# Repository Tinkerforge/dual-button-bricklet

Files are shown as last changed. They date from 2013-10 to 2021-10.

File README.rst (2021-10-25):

Dual Button Bricklet
====================

This repository contains the firmware source code and the hardware design
files. The documentation generator configs can be found at
https://github.com/Tinkerforge/generators

Repository Content
------------------

software/:
 * examples/: Examples for all supported languages
 * build/: Compiled files
 * src/: Source code of firmware
 * Makefile: Makefile to build project

hardware/:
 * Contains KiCad project files and additionally schematics as PDF

datasheets/:
 * Contains datasheets for sensors and complex ICs that are used

Hardware
--------

The hardware is designed with the open source EDA Suite KiCad
(http://www.kicad.org). Before you are able to open the files,
you have to install the Tinkerforge kicad-libraries
(https://github.com/Tinkerforge/kicad-libraries). You can either clone
them directly in hardware/ or clone them in a separate folder and
symlink them into hardware/
(ln -s kicad_path/kicad-libraries project_path/hardware). After that you
can open the .pro file in hardware/ with KiCad and from there view and
modify the schematics and the PCB layout.

Software
--------

If you want to do your own Brick/Bricklet firmware development we highly
recommend that you use our build environment setup script and read the
tutorial (https://www.tinkerforge.com/en/doc/Tutorials/Tutorial_Build_Environment/Tutorial.html).

To compile the C code we recommend you to install the newest GNU Arm Embedded
Toolchain (https://launchpad.net/gcc-arm-embedded/+download).
You also need to install bricklib (https://github.com/Tinkerforge/bricklib)
and brickletlib (https://github.com/Tinkerforge/brickletlib).

You can either clone it directly in software/src/ or clone it in a
separate folder and symlink it into software/src/
(ln -s bricklib_path/bricklib project_path/software/src/ and
ln -s brickletlib_path/brickletlib project_path/software/src/).
Finally make sure to have CMake installed
(http://www.cmake.org/cmake/resources/software.html).

After that you can build the firmware by invoking make in software/.
The firmware (.bin) can then be found in software/build/ and uploaded
with brickv (click button "Flashing" on start screen).

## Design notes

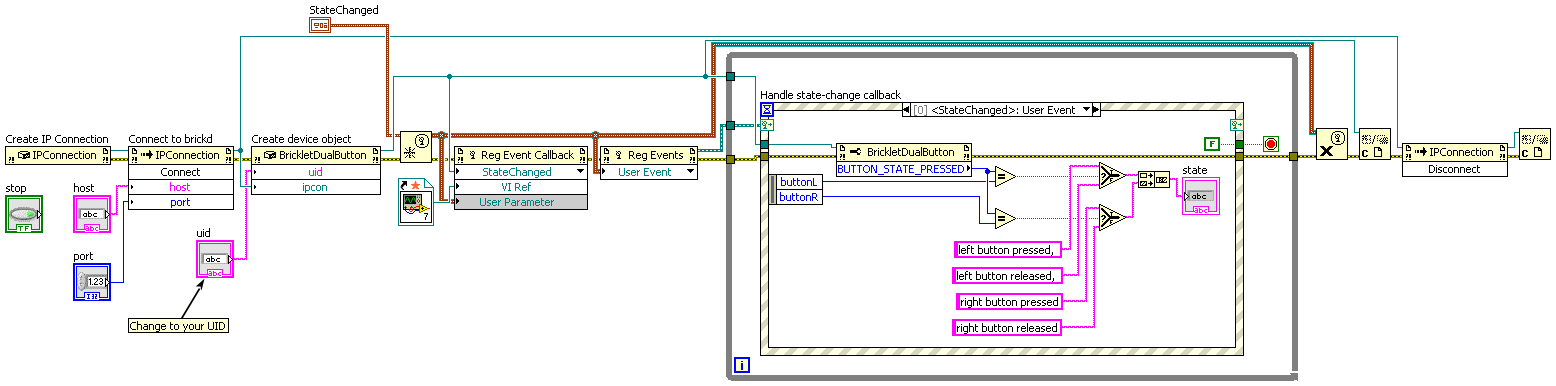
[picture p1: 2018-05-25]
software/examples/labview/Example Callback.vi.png

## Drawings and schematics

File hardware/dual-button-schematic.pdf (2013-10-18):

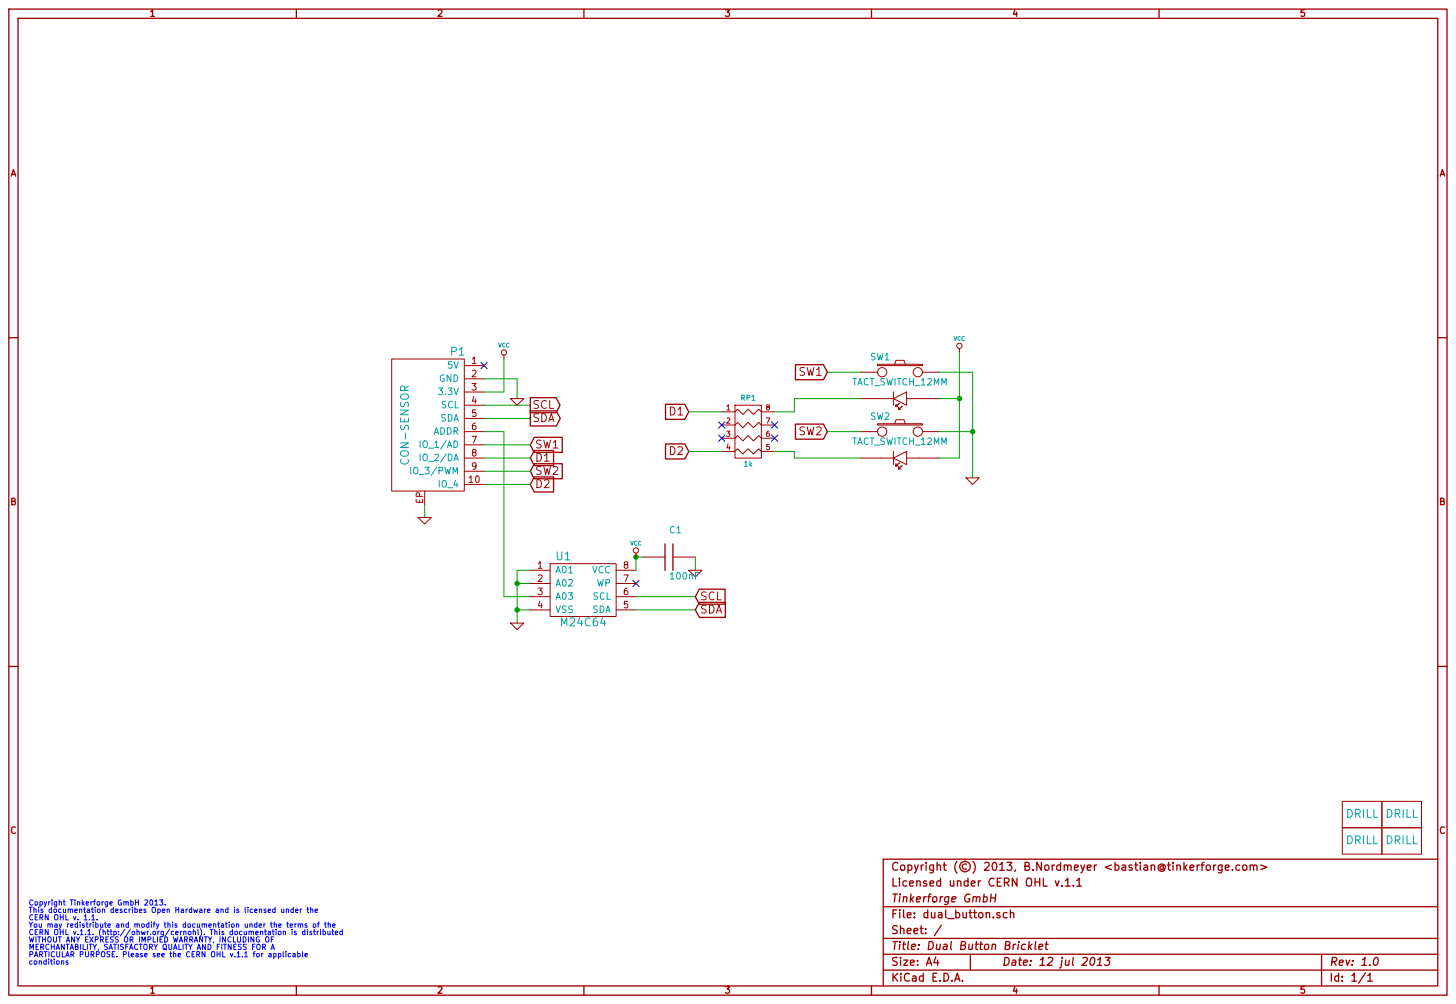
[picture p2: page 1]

Copyright (©) 2013, B.Nordmeyer <bastian@tinkerforge.com>
Licensed under CERN OHL v.1.1
Tinkerforge GmbH
Id: 1/1 Title: Dual Button Bricklet File: dual_button.sch
Sheet: /

Copyright Tinkerforge GmbH 2013. This documentation describes Open Hardware and is licensed under the CERN OHL v. 1.1. You may redistribute and modify this documentation under the terms of the CERN OHL v.1.1. (http://ohwr.org/cernohl). This documentation is distributed WITHOUT ANY EXPRESS OR IMPLIED WARRANTY, INCLUDING OF MERCHANTABILITY, SATISFACTORY QUALITY AND FITNESS FOR A

PARTICULAR PURPOSE. Please see the CERN OHL v.1.1 for applicable

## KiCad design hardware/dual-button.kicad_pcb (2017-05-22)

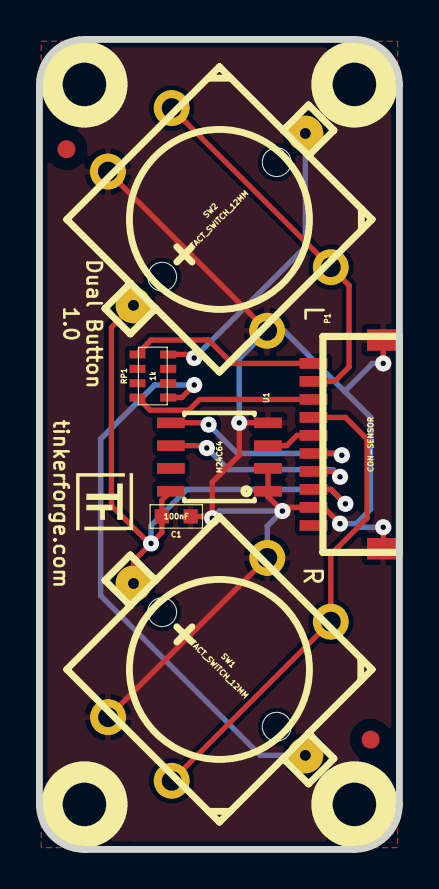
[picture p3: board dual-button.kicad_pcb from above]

Board: 2 copper layers, 20.0 x 45.0 mm, 15 parts (0 on the bottom side), 11 nets.

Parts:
C1: 100nF; 0603
Fiducial_Mark: VAL**; Fiducial_Mark
Fiducial_Mark#2: VAL**; Fiducial_Mark
P1: CON-SENSOR
RP1: 1k; 4X0603
Ref**: Val**; Logo_31x31
SW1, SW2: TACT_SWITCH_12MM; TACT_SWITCH_12mm
U1: M24C64; SOIC8
U2, U3, U4, U5: DRILL; DRILL_NP
VAL: WEEE_7mm
VAL#2: CE_5mm

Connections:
D1: P1.8, RP1.1
D2: P1.10, RP1.4
GND: C1.1, P1.2, P1.EP, SW1.3, SW2.3, U1.1, U1.2, U1.4
unnamed: RP1.5, SW2.2
unnamed: RP1.8, SW1.2
unnamed: P1.6, U1.3
SCL: P1.4, U1.6
SDA: P1.5, U1.5
SW1: P1.7, SW1.4
SW2: P1.9, SW2.4
VCC: C1.2, P1.3, SW1.1, SW2.1, U1.8

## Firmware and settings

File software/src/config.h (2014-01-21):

/* dual-button-bricklet
 * Copyright (C) 2013 Olaf Lüke <olaf@tinkerforge.com>
 *
 * config.h: Dual Button Bricklet specific configuration
 *
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
 * You should have received a copy of the GNU Lesser General Public
 * License along with this library; if not, write to the
 * Free Software Foundation, Inc., 59 Temple Place - Suite 330,
 * Boston, MA 02111-1307, USA.
 */

#ifndef CONFIG_H
#define CONFIG_H

#include <stdint.h>
#include <stdbool.h>

#include "bricklib/drivers/board/sam3s/SAM3S.h"

#include "dual-button.h"

#define BRICKLET_FIRMWARE_VERSION_MAJOR 2
#define BRICKLET_FIRMWARE_VERSION_MINOR 0
#define BRICKLET_FIRMWARE_VERSION_REVISION 2

#define BRICKLET_HARDWARE_VERSION_MAJOR 1
#define BRICKLET_HARDWARE_VERSION_MINOR 0
#define BRICKLET_HARDWARE_VERSION_REVISION 0

#define BRICKLET_DEVICE_IDENTIFIER 230

#define PIN_BUTTON_R (BS->pin1_ad)
#define PIN_LED_R    (BS->pin2_da)
#define PIN_BUTTON_L (BS->pin3_pwm)
#define PIN_LED_L    (BS->pin4_io)

#define LOGGING_LEVEL LOGGING_DEBUG
#define DEBUG_BRICKLET 0

#define BRICKLET_NO_OFFSET
#define INVOCATION_IN_BRICKLET_CODE

typedef struct {
	uint8_t button_r;
	uint8_t button_l;
	uint8_t led_r;
	uint8_t led_l;

	uint16_t button_r_debounce;
	uint16_t button_l_debounce;

	bool state_changed;

	uint32_t tick;
} BrickContext;

#endif

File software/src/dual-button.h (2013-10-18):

/* dual-button-bricklet
 * Copyright (C) 2013 Olaf Lüke <olaf@tinkerforge.com>
 *
 * dual-button.h: Implementation of Dual Button Bricklet messages
 *
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
 * You should have received a copy of the GNU Lesser General Public
 * License along with this library; if not, write to the
 * Free Software Foundation, Inc., 59 Temple Place - Suite 330,
 * Boston, MA 02111-1307, USA.
 */

#ifndef DUAL_BUTTON_H
#define DUAL_BUTTON_H

#include <stdint.h>
#include "bricklib/com/com_common.h"

#define BUTTON_L 0
#define BUTTON_R 1

#define LED_L 0
#define LED_R 1

#define BUTTON_STATE_PRESSED 0
#define BUTTON_STATE_RELEASED 1

#define BUTTON_DEBOUNCE_TIME 25 // in ms

#define LED_STATE_AUTO_TOGGLE_ON 0
#define LED_STATE_AUTO_TOGGLE_OFF 1
#define LED_STATE_ON 2
#define LED_STATE_OFF 3

#define FID_SET_LED_STATE 1
#define FID_GET_LED_STATE 2
#define FID_GET_BUTTON_STATE 3
#define FID_STATE_CHANGED 4
#define FID_SET_SELECTED_LED_STATE 5

typedef struct {
	MessageHeader header;
} __attribute__((__packed__)) StandardMessage;

typedef struct {
	MessageHeader header;
	uint8_t led_l;
	uint8_t led_r;
} __attribute__((__packed__)) SetLEDState;

typedef struct {
	MessageHeader header;
} __attribute__((__packed__)) GetLEDState;

typedef struct {
	MessageHeader header;
	uint8_t led_l;
	uint8_t led_r;
} __attribute__((__packed__)) GetLEDStateReturn;

typedef struct {
	MessageHeader header;
} __attribute__((__packed__)) GetButtonState;

typedef struct {
	MessageHeader header;
	uint8_t button_l;
	uint8_t button_r;
} __attribute__((__packed__)) GetButtonStateReturn;

typedef struct {
	MessageHeader header;
	uint8_t button_l;
	uint8_t button_r;
	uint8_t led_l;
	uint8_t led_r;
} __attribute__((__packed__)) StateChanged;

typedef struct {
	MessageHeader header;
	uint8_t led;
	uint8_t state;
} __attribute__((__packed__)) SetSelectedLEDState;

void set_led_state(const ComType com, const SetLEDState *data);
void get_led_state(const ComType com, const GetLEDState *data);
void get_button_state(const ComType com, const GetButtonState *data);
void set_selected_led_state(const ComType com, const SetSelectedLEDState *data);

void next_led_toggle_state(const uint8_t button);
void send_state_changed_callback(void);

void invocation(const ComType com, const uint8_t *data);
void constructor(void);
void destructor(void);
void tick(const uint8_t tick_type);

#endif

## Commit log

2013-07-23 Initial commit for Dual Button Bricklet
2013-07-23 Add prototype disclaimer to README.rst
2013-09-11 Add examples for Dual Button Bricklet
2013-10-15 hardware files checkin
    [dual_button.kicad_pcb, dual_button.sch]
2013-10-17 Change default LED state to auto-toggle-off
2013-10-18 Add SetSelectedLEDState API for Dual Button Bricklet
2014-01-20 Fix mixup in firmware/hardware version
    [config.h]
2014-01-21 Fix left/right button permutation
    [config.h]
2014-04-02 perl: Unify print style
2015-08-07 Use full device class name in Python example
2016-05-18 c: Add missing device destroy call
2017-05-22 add button diameter marking
    [dual_button.kicad_pcb]
2018-02-20 Cleanup KiCad libraries config
    Ensure LibDir=kicad-libraries and LibName1=tinkerforge.
    Remove special library.
2018-05-11 Rename files
    [dual-button.kicad_pcb, dual-button.sch]
2018-05-28 examples: Unify constant printing style
2021-10-25 Update KiCad link
    https://www.kicad.org/blog/2021/10/Avoid-links-to-former-kicad-domain/
